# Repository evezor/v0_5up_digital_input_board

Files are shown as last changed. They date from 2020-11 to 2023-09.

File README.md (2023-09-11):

# 5up Digital Input Board
*please note this board has been deprecated.

An edge board containing five opto isolated inputs.  All inputs are active HIGH. Each input comes with an input pin, a 5v and a gnd connection. 

If I were to do this again, I would probably make a jumper that can switch between the 5v and whatever the bus voltage was. 

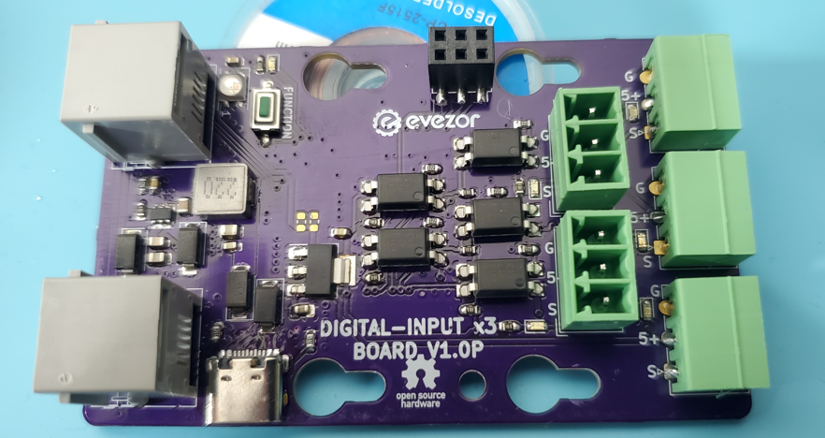
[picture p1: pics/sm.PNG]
sm


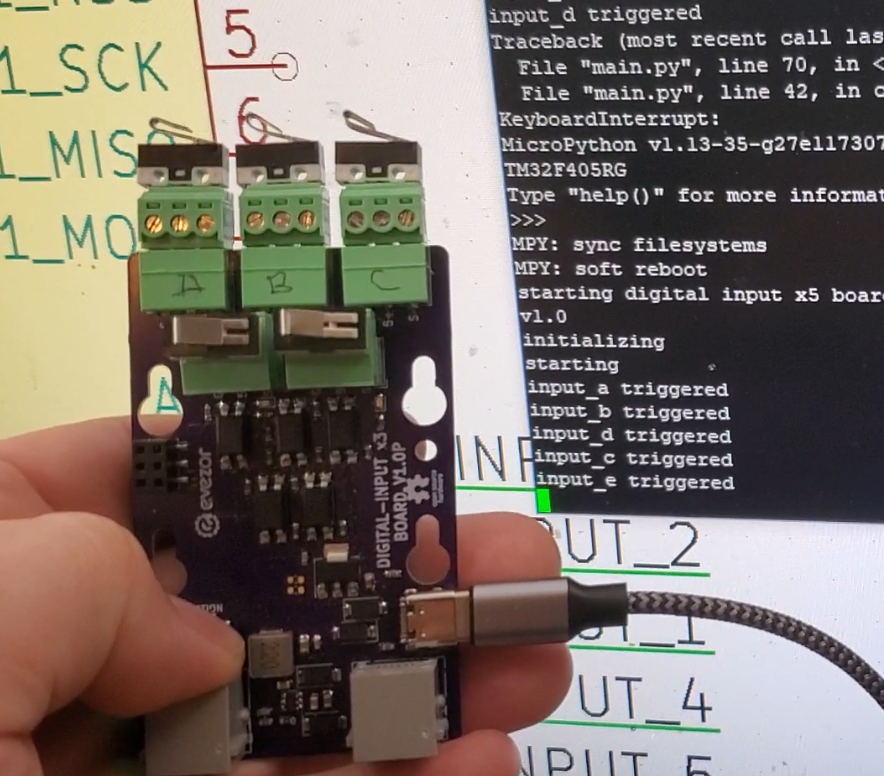
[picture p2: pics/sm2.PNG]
sm2


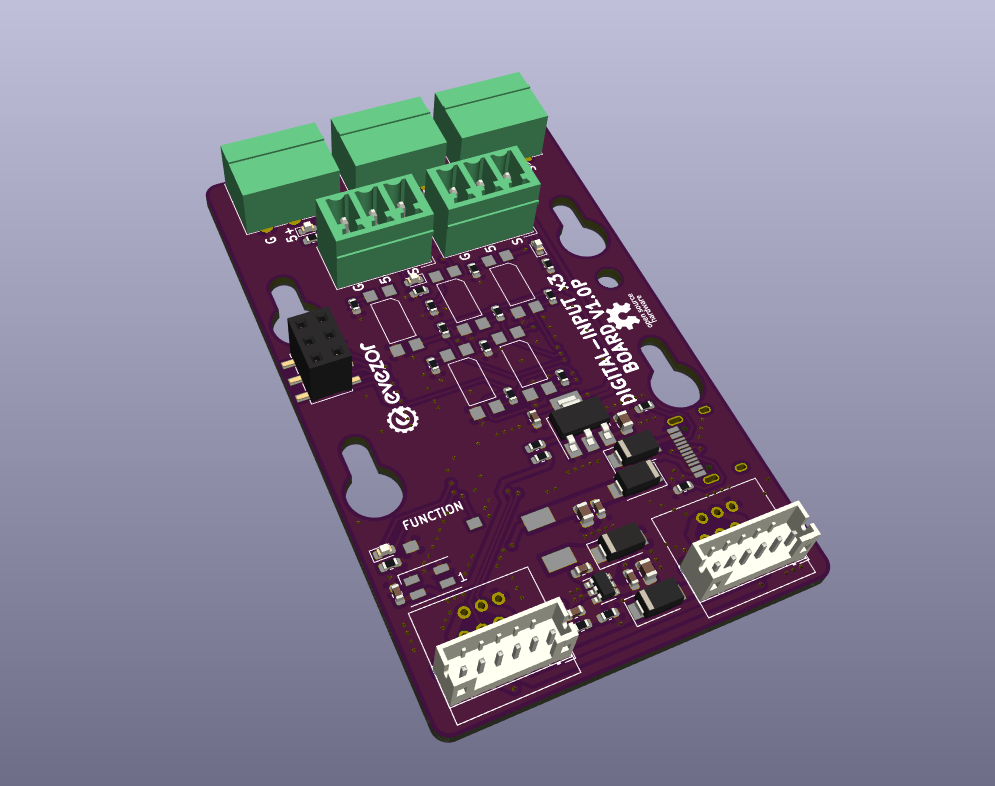
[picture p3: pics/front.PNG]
front


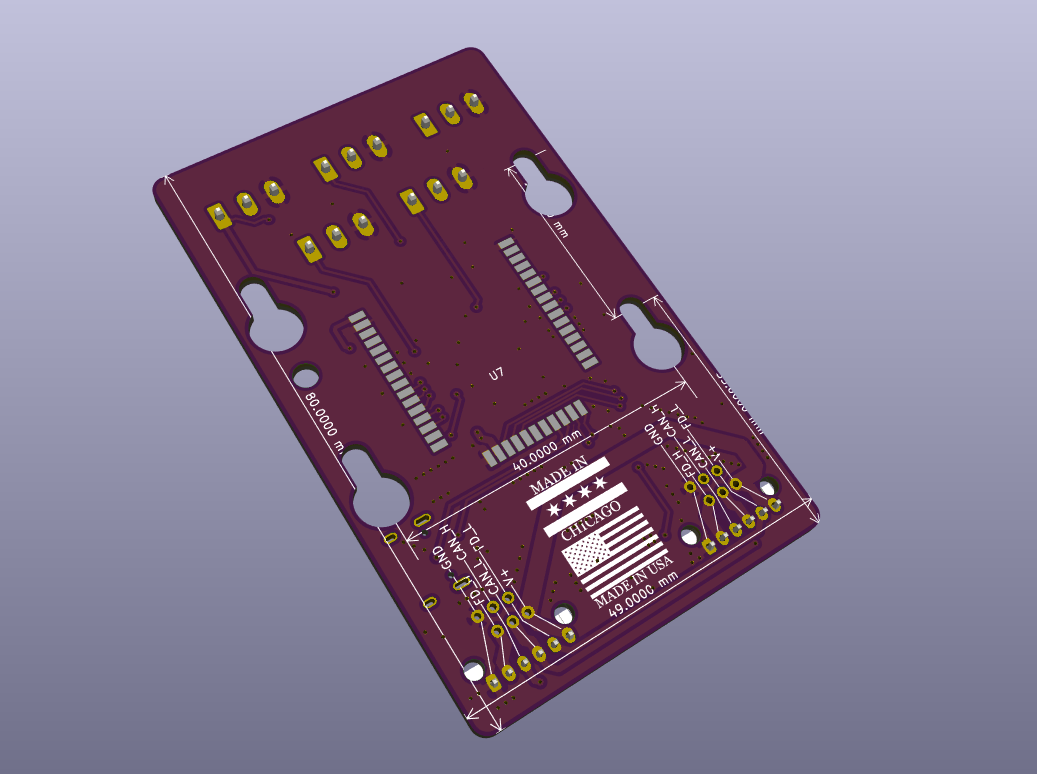
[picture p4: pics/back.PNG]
back


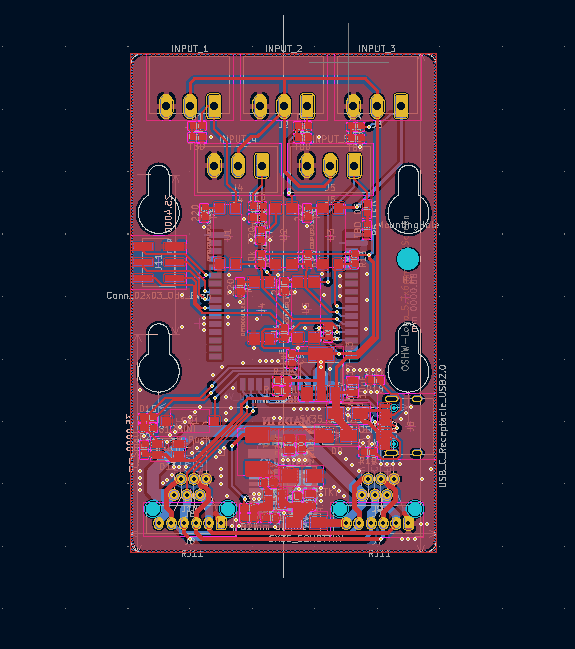
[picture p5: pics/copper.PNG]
copper


sch

source files can be found here: https://github.com/evezor/v0_5up_digital_input_board

This board uses the Evezor Stamp STMF405 MCU

source: https://github.com/evezor/Evezor-Stamp-STMF405

Evezor® and all associated marks, logos, and designs are registered trademarks and protected by copyright. Unauthorized use or reproduction of these trademarks and copyrighted materials is strictly prohibited.

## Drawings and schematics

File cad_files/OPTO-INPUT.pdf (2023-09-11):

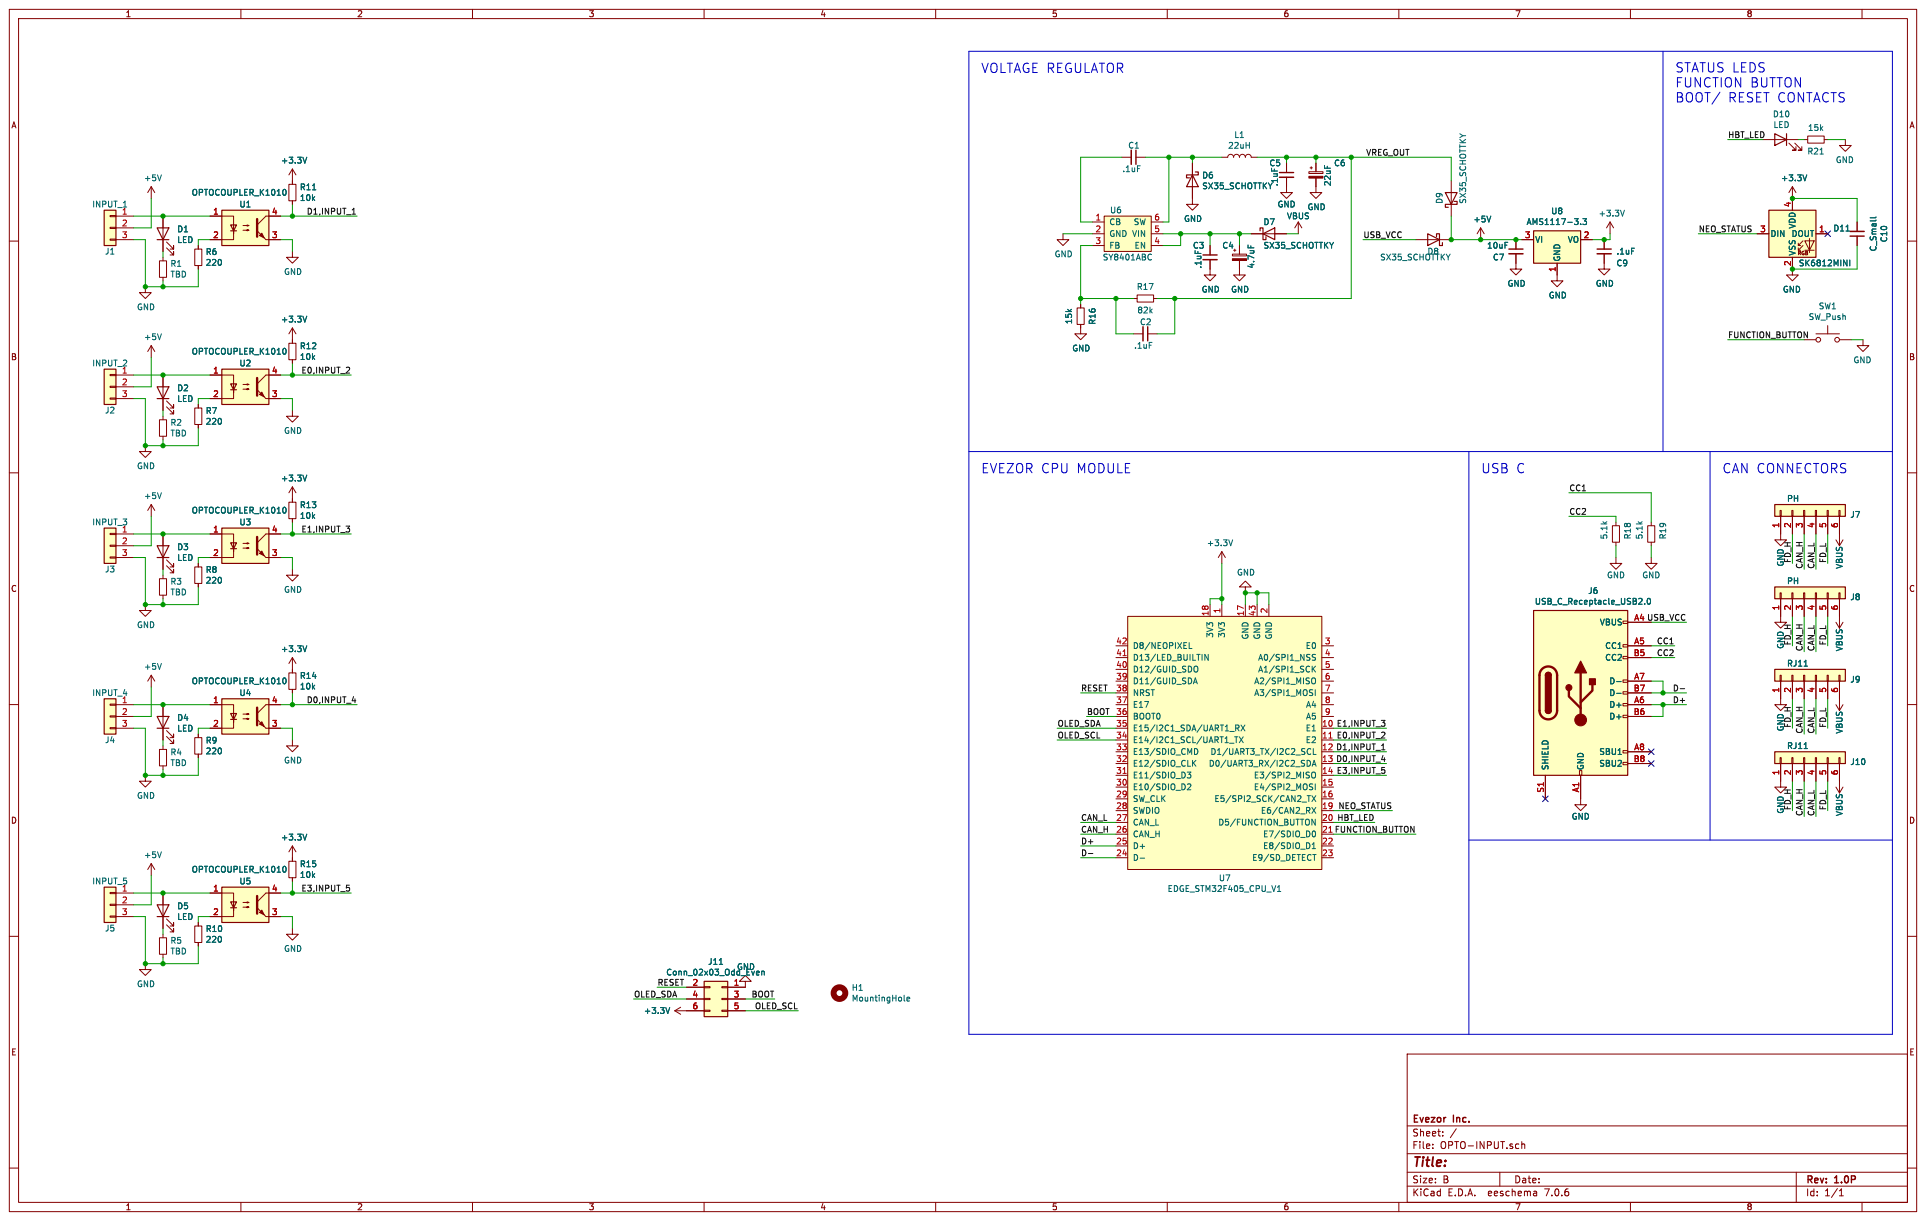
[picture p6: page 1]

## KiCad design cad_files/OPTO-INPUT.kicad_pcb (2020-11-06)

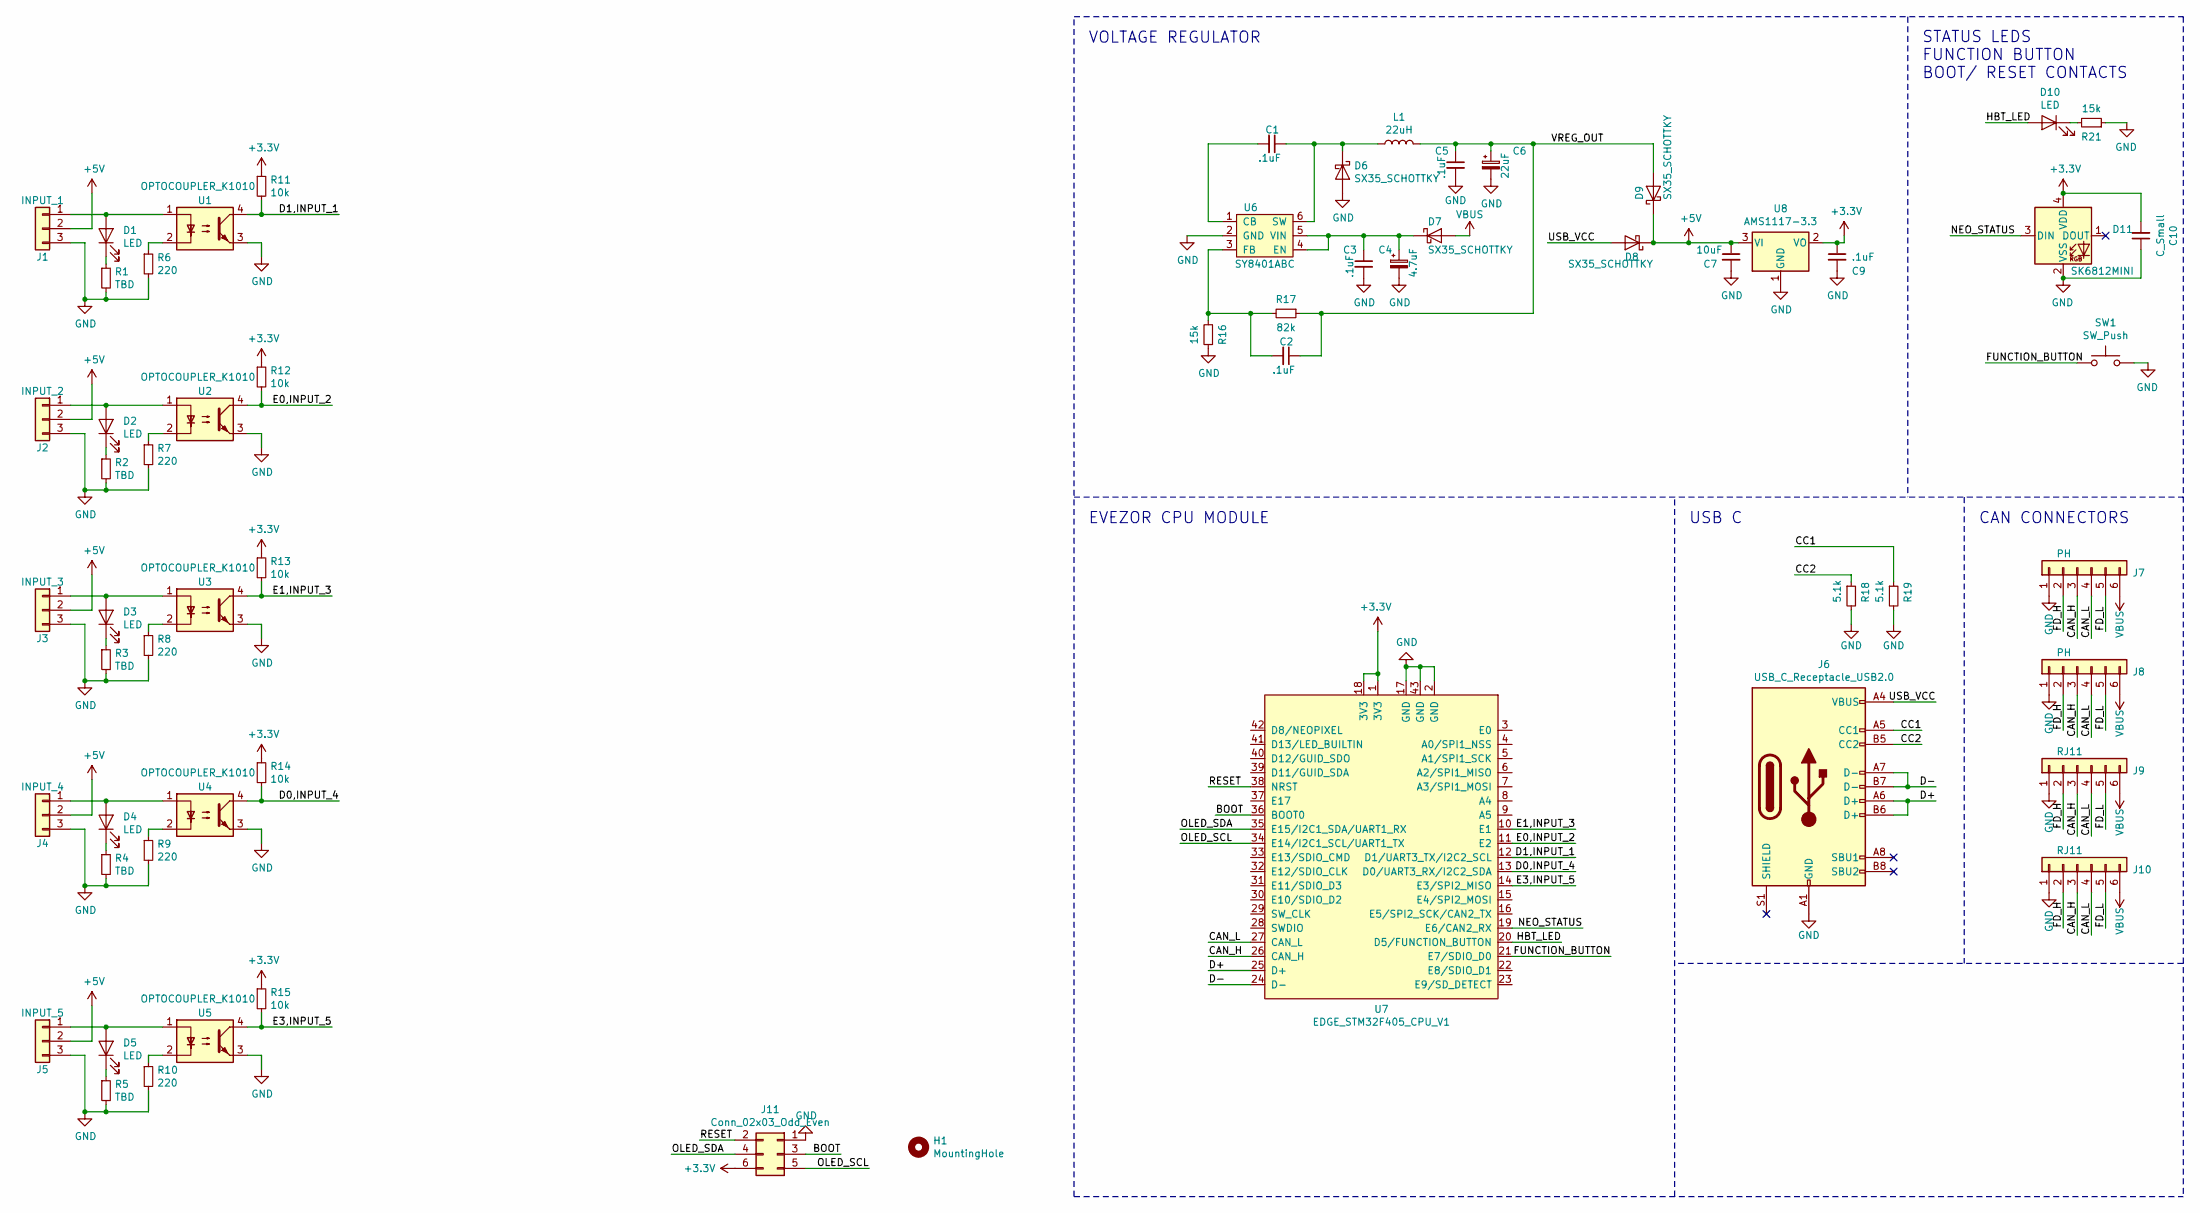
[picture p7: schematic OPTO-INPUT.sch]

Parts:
C1, C2, C3, C5, C9: .1uF; C_0603_1608Metric
C4: 4.7uF; C_0805_2012Metric
C6: 22uF; C_0805_2012Metric
C7: 10uF; C_0805_2012Metric
C10: C_Small; C_0603_1608Metric
D1, D2, D3, D4, D5, D10: LED; LED_0603_1608Metric
D6, D7, D8, D9: SX35_SCHOTTKY; D_SMA
D11: SK6812MINI; LED_SK6812MINI_PLCC4_3.5x3.5mm_P1.75mm
H1: MountingHole; OLED_STANDOFF
J1: INPUT_1; PhoenixContact_MC_1,5_3-G-3.81_1x03_P3.81mm_Horizontal
J2: INPUT_2; PhoenixContact_MC_1,5_3-G-3.81_1x03_P3.81mm_Horizontal
J3: INPUT_3; PhoenixContact_MC_1,5_3-G-3.81_1x03_P3.81mm_Horizontal
J4: INPUT_4; PhoenixContact_MCV_1,5_3-G-3.81_1x03_P3.81mm_Vertical
J5: INPUT_5; PhoenixContact_MCV_1,5_3-G-3.81_1x03_P3.81mm_Vertical
J6: USB_C_Receptacle_USB2.0; USB_C_Receptacle_HRO_TYPE-C-31-M-12
J7, J8: PH; JST_PH_B6B-PH-K_1x06_P2.00mm_Vertical
J9, J10: RJ11; RJ11_C189747_Horizontal
J11: Conn_02x03_Odd_Even; OLED_HEADER
L1: 22uH; INDUCTOR_7.5X6.6_GCDA0630-220MC
R1, R2, R3, R4, R5: TBD; R_0603_1608Metric
R6, R7, R8, R9, R10: 220; R_0603_1608Metric
R11, R12, R13, R14, R15: 10k; R_0603_1608Metric
R16, R21: 15k; R_0603_1608Metric
R17: 82k; R_0603_1608Metric
R18, R19: 5.1k; R_0603_1608Metric
SW1: SW_Push; SWITCH_2x3_SMD_TACTILE_GREEN
U1, U2, U3, U4, U5: OPTOCOUPLER_K1010; OPTOCOUPLER_K10104CTLD
U6: SY8401ABC; SOT-23-6
U7: EDGE_STM32F405_CPU_V1; EDGE_STAMP
U8: AMS1117-3.3; SOT-223-3_TabPin2

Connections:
+3V3: C9.1, C10.2, D11.4 (VDD), J11.6, R11.1, R12.1, R13.1, R14.1, R15.1, U7.1 (3V3), U7.18 (3V3), U8.2 (VO); also elsewhere on the board
+5V: C7.1, D8.1 (K), D9.1 (K), J1.2, J2.2, J3.2, J4.2, J5.2, U8.3 (VI)
/BOOT: J11.3, U7.36 (BOOT0)
/CAN_H: J7.3, J8.3, J9.3, J10.3, U7.26 (CAN_H)
/CAN_L: J7.4, J8.4, J9.4, J10.4, U7.27 (CAN_L)
/CC1: J6.A5 (CC1), R19.1
/CC2: J6.B5 (CC2), R18.1
/D0,INPUT_4: R14.2, U4.4, U7.13 (D0/UART3_RX/I2C2_SDA)
/D1,INPUT_1: R11.2, U1.4, U7.12 (D1/UART3_TX/I2C2_SCL)
/D+: J6.A6 (D+), J6.B6 (D+), U7.25 (D+)
/D-: J6.A7 (D-), J6.B7 (D-), U7.24 (D-)
/E0,INPUT_2: R12.2, U2.4, U7.11 (E2)
/E1,INPUT_3: R13.2, U3.4, U7.10 (E1)
/E3,INPUT_5: R15.2, U5.4, U7.14 (E3/SPI2_MISO)
/FD_H: J7.2, J8.2, J9.2, J10.2
/FD_L: J7.5, J8.5, J9.5, J10.5
/FUNCTION_BUTTON: SW1.1, U7.21 (E7/SDIO_D0)
/HBT_LED: D10.2 (A), U7.20 (D5/FUNCTION_BUTTON)
/NEO_STATUS: D11.3 (DIN), U7.19 (E6/CAN2_RX)
/OLED_SCL: J11.5, U7.34 (E14/I2C1_SCL/UART1_TX)
/OLED_SDA: J11.4, U7.35 (E15/I2C1_SDA/UART1_RX)
/RESET: J11.2, U7.38 (NRST)
/USB_VCC: D8.2 (A), J6.A4 (VBUS), J6.A9 (VBUS), J6.B4 (VBUS), J6.B9 (VBUS)
/VREG_OUT: C2.1, C5.1, C6.1, D9.2 (A), L1.2, R17.1
GND: C3.2, C4.2, C5.2, C6.2, C7.2, C9.2, C10.1, D6.2 (A), D11.2 (VSS), J1.3, J2.3, J3.3, J4.3, J5.3, J6.A1 (GND), J6.A12 (GND), J6.B1 (GND), J6.B12 (GND), J7.1, J8.1, J9.1, J10.1, J11.1, R1.2, R2.2, R3.2, R4.2, R5.2, R6.2, R7.2, R8.2, R9.2, R10.2, R16.1, R18.2, R19.2, R21.1, SW1.2, U1.3, U2.3, U3.3, U4.3, U5.3, U6.2 (GND), U7.2 (GND), U7.17 (GND), U7.43 (GND), U8.1 (GND)
unnamed: C1.1, D6.1 (K), L1.1, U6.6 (SW)
unnamed: C1.2, U6.1 (CB)
unnamed: C2.2, R16.2, R17.2, U6.3 (FB)
unnamed: C3.1, C4.1, D7.1 (K), U6.4 (EN), U6.5 (VIN)
unnamed: D1.1 (K), R1.1
unnamed: D1.2 (A), J1.1, U1.1
unnamed: D2.1 (K), R2.1
unnamed: D2.2 (A), J2.1, U2.1
unnamed: D3.1 (K), R3.1
unnamed: D3.2 (A), J3.1, U3.1
unnamed: D4.1 (K), R4.1
unnamed: D4.2 (A), J4.1, U4.1
unnamed: D5.1 (K), R5.1
unnamed: D5.2 (A), J5.1, U5.1
unnamed: D10.1 (K), R21.2
unnamed: R6.1, U1.2
unnamed: R7.1, U2.2
unnamed: R8.1, U3.2
unnamed: R9.1, U4.2
unnamed: R10.1, U5.2
VBUS: D7.2 (A), J7.6, J8.6, J9.6, J10.6

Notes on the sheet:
EVEZOR CPU MODULE
USB C
CAN CONNECTORS
STATUS LEDS FUNCTION BUTTON BOOT/ RESET CONTACTS
VOLTAGE REGULATOR

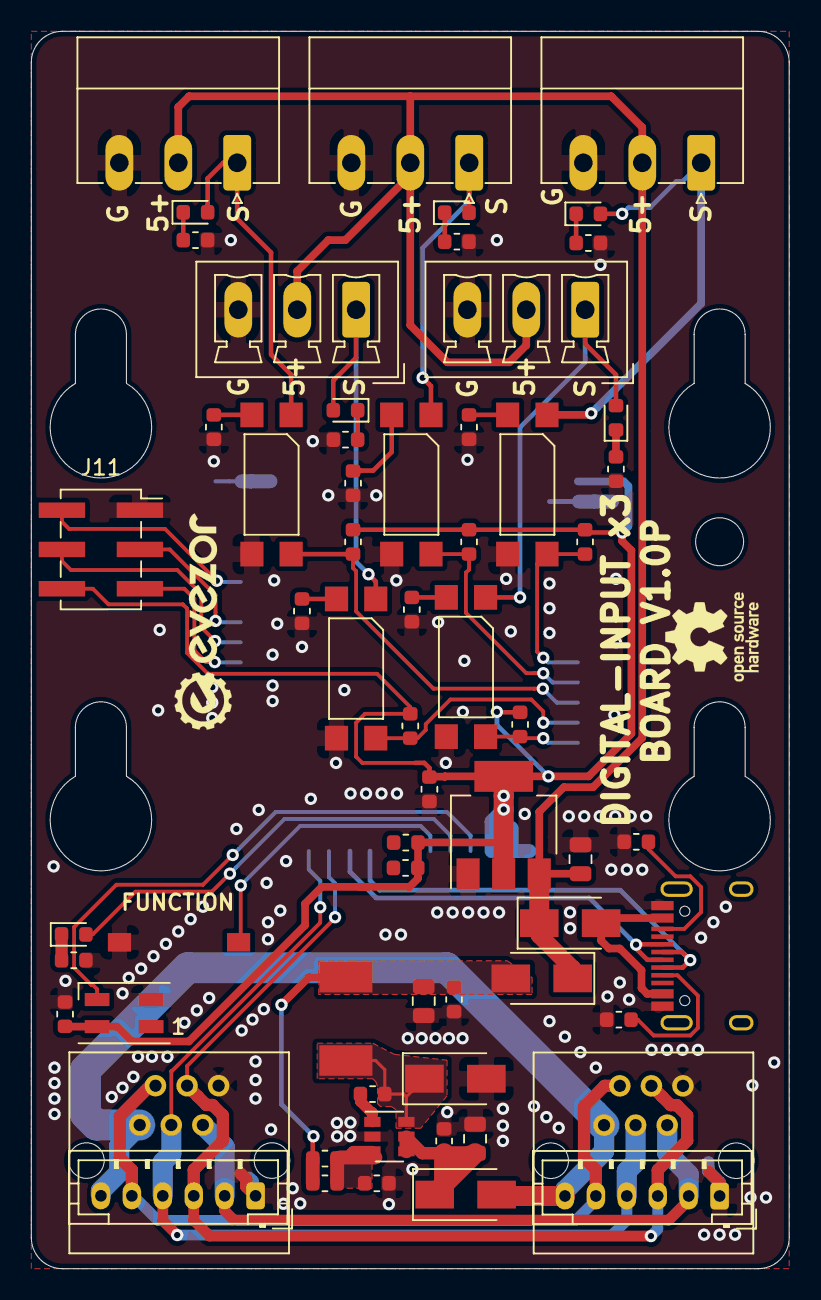
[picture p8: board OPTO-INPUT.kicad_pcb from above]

Board: 2 copper layers, 49.0 x 80.0 mm, 64 parts (1 on the bottom side), 46 nets.

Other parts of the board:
R20, R22: R_Small; R_0603_1608Metric

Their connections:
+3V3: R20.2, R22.2; also elsewhere on the board

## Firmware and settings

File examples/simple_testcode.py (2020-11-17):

#5up Digital Input v1.0p test code

from machine import Pin
from pyb import CAN, ADC
import utime


print("starting digital input x5 board test")
print("v1.0")
print("initializing")
can = CAN(1, CAN.NORMAL)
can.setfilter(0, CAN.LIST16, 0, (123, 124, 125, 126))


#Setup Pins
hbt_led = Pin("D5", Pin.OUT)
func_butt = Pin("E7", Pin.IN, Pin.PULL_UP) 
can_wakeup = Pin("D6", Pin.OUT)
can_wakeup.value(0) 

input_a = Pin("D1", Pin.IN)
input_b = Pin("E2", Pin.IN)
input_c = Pin("E1", Pin.IN)
input_d = Pin("D0", Pin.IN)
input_e = Pin("E3", Pin.IN)


#Setup hbt timer
hbt_state = 0
hbt_interval = 500
start = utime.ticks_ms()
next_hbt = utime.ticks_add(start, hbt_interval)
hbt_led.value(hbt_state)


print("starting")


def chk_hbt():
    global next_hbt
    global hbt_state
    now = utime.ticks_ms()
    if utime.ticks_diff(next_hbt, now) <= 0:
        if hbt_state == 1:
            hbt_state = 0
            hbt_led.value(hbt_state)
            #print("hbt")
        else:
            hbt_state = 1
            hbt_led.value(hbt_state)  
        
        next_hbt = utime.ticks_add(next_hbt, hbt_interval)

def chk_buttons():
    global next_button_chk
    now = utime_ms()
    if utime.ticks_diff(next_button_chk, now) <= 0:
        pass
        

def send():
    can.send('EVZRTEST', 123)   # send a message with id 123
    
def get():
    mess = can.recv(0)
    print(mess)
    blink_fast()
        
def blink_fast():
    for i in range(30):
        hbt_led.value(1)
        utime.sleep_ms(50)
        hbt_led.value(0)
        utime.sleep_ms(50)
      
while True:
    chk_hbt()
    if not (func_butt.value()):
        print("function button")
        send()
        blink_fast()
        utime.sleep_ms(200)
    
    if(can.any(0)):
        get()
    
    
    if not (input_a.value()):
        print("input_a triggered")
        utime.sleep_ms(200)
    if not (input_b.value()):
        print("input_b triggered")
        utime.sleep_ms(200)
    if not (input_c.value()):
        print("input_c triggered")
        utime.sleep_ms(200)
    if not (input_d.value()):
        print("input_d triggered")
        utime.sleep_ms(200)
    if not (input_e.value()):
        print("input_e triggered")
        utime.sleep_ms(200)
